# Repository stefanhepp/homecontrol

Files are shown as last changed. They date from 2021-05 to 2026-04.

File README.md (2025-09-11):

HomeControl
===========

This is the sourcecode and plans for my home automation system.

Content
=======

- `homecontrol`: Sources and schematics for a simple AtMega based home automation controller with 8 24VDC digital inputs, 8 24VDC digital outputs (open collector), RS232 and 2 230VAC sense inputs.
- `pixtend`: Sources for the main controller, based on an PiXtend v2-S with Raspberry 3B, written in Python. Connects via RS232 and MQTT to the network.

Installation Pixtend OS
=======================

- Install Raspbian OS (64bit)
   - `sudo rpi-imager`: Enable SSH, set hostname, username, password
- Setup Rasbian, install software
  ```
  # Enable SPI, UART, console bootup, set locale
  sudo raspi-config
  sudo apt install vim screen git gpiod libgpiod-dev python3-dev python3-pip python3-paho-mqtt
  ```
- Install Pixtend Python library
  ```
  git clone https://git.kontron-electronics.de/sw/ked/raspberry-pi/pixtend-v2/pplv2.git
  cd pplv2
  git checkout 0.1.6-dev
  python setup.py bdist_wheel
  # Install into venv
  python -m venv ~/.venv
  source ~/.venv/bin/activate
  pip install dist/pixtendlibv2-0.1.6-py3-none-any.whl
  ```
- Install pixcontrol script
  ```
  # Install prerequisites
  . ~/.venv/bin/activate
  pip install pyserial paho-mqtt
  cd ~/homecontrol/pixtend
  sudo cp pixcontrol.service /etc/systemd/system/
  sudo systemctl enable pixcontrol
  ```

License
=======

This program is free software: you can redistribute it and/or modify
it under the terms of the GNU General Public License as published by
the Free Software Foundation, either version 3 of the License, or
(at your option) any later version.

This program is distributed in the hope that it will be useful,
but WITHOUT ANY WARRANTY; without even the implied warranty of
MERCHANTABILITY or FITNESS FOR A PARTICULAR PURPOSE.  See the
GNU General Public License for more details.

You should have received a copy of the GNU General Public License
along with this program.  If not, see <https://www.gnu.org/licenses/>.

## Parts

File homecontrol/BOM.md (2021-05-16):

Parts for HomeControl
=====================

Case
----
- DMB-4773-CC
  Datasheet: https://www.budind.com/pdf/hb4773.pdf
  Digikey: https://www.digikey.at/product-detail/de/bud-industries/DMB-4773/377-1810-ND/2499329

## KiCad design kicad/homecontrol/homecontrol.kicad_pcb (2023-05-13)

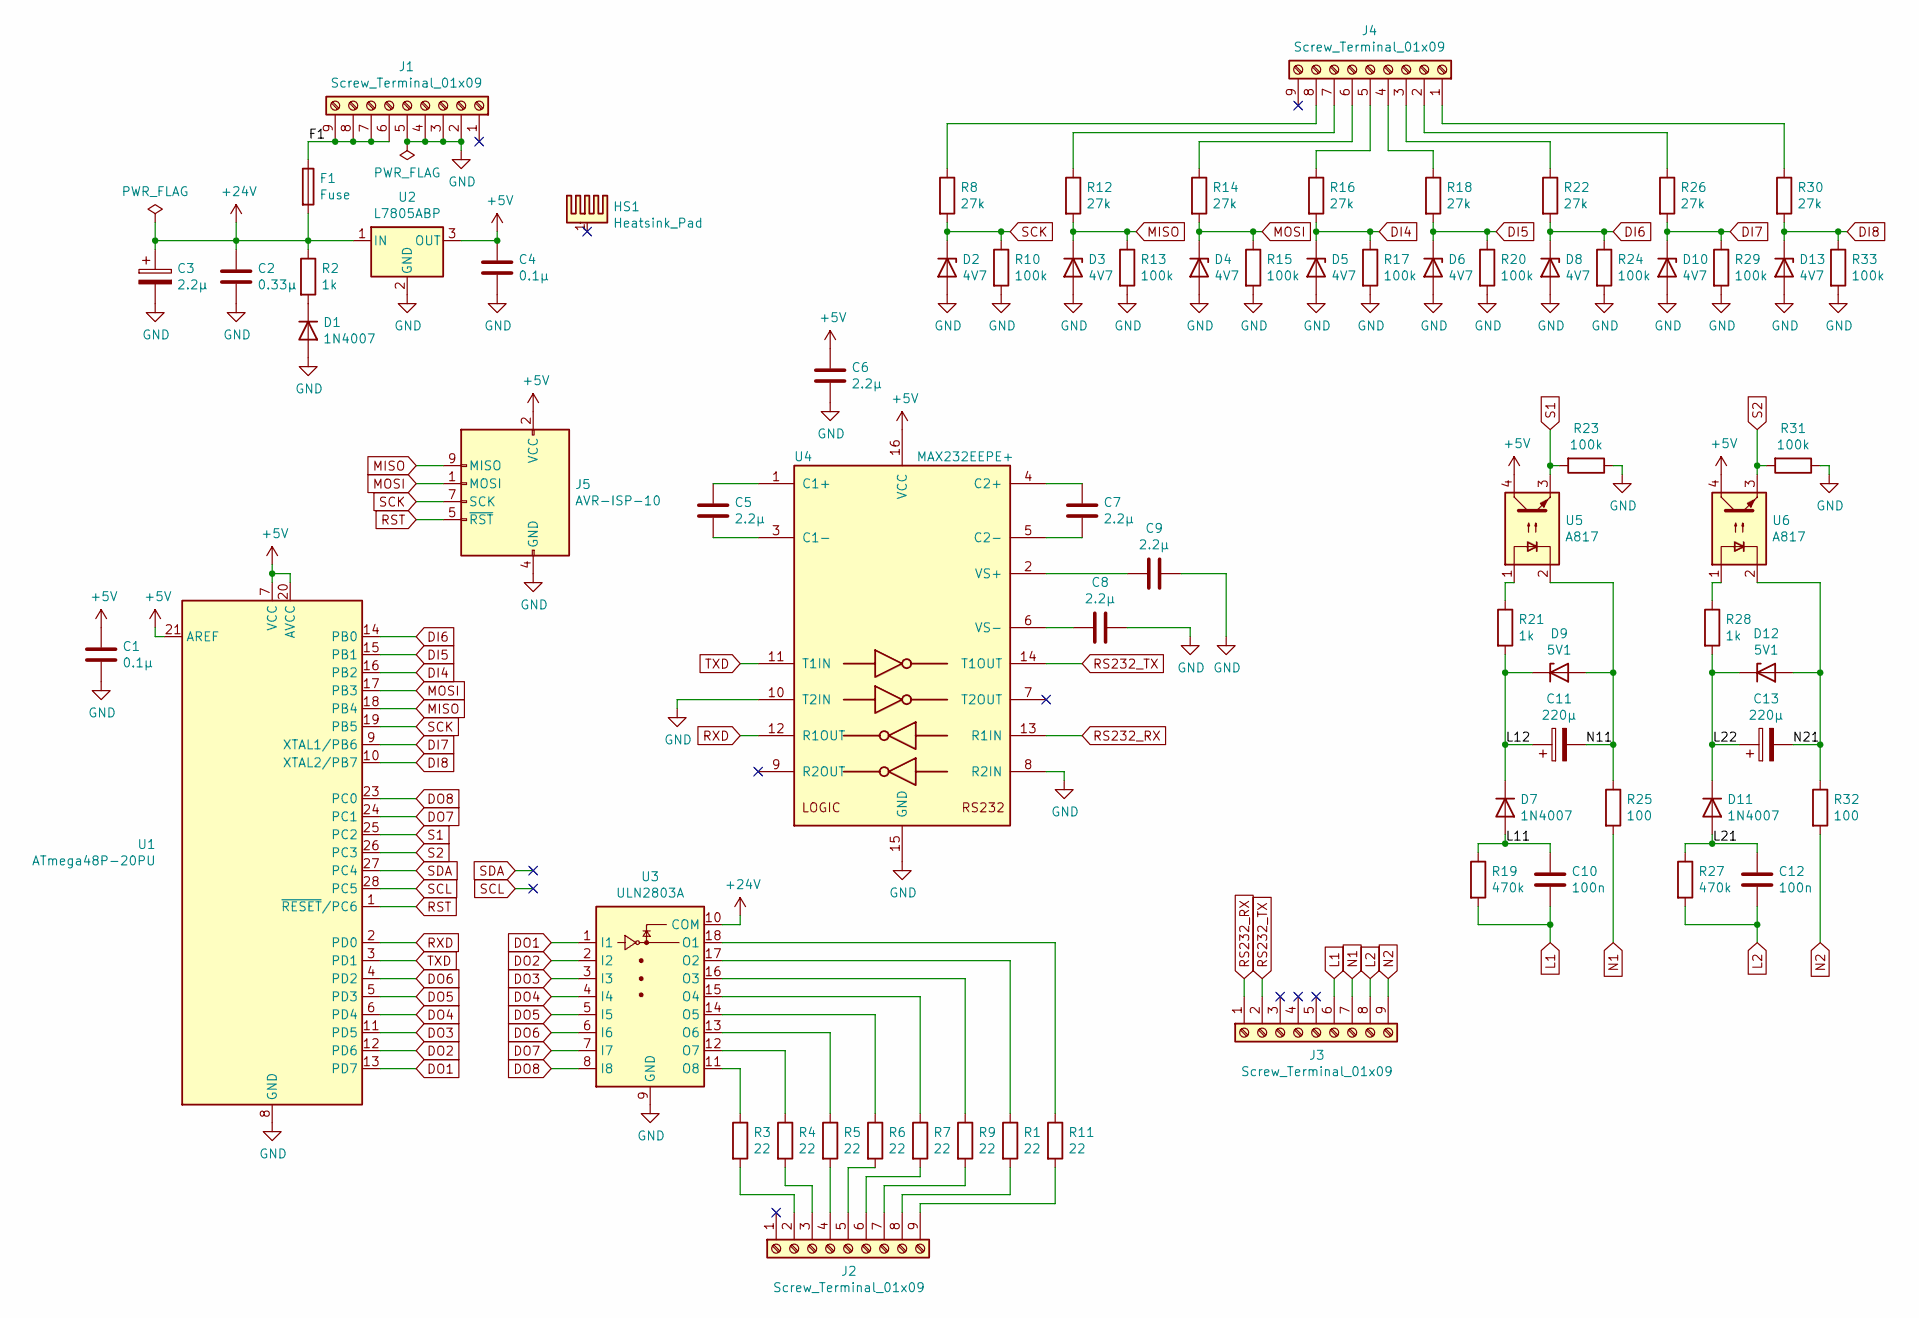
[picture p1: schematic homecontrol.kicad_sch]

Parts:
C1, C4: 0.1µ; C_Rect_L7.0mm_W2.5mm_P5.00mm; Voltage 50V
C2: 0.33µ; C_Disc_D4.7mm_W2.5mm_P5.00mm; Voltage 50V
C3: 2.2µ; CP_Radial_D6.3mm_P2.50mm; Voltage 50V
C5, C6, C7, C8, C9: 2.2µ; C_Rect_L4.6mm_W3.0mm_P2.50mm_MKS02_FKP02; Voltage 50V
C10, C12: 100n; C_Rect_L19.0mm_W6.0mm_P15.00mm_MKS4; Voltage 250V
C11, C13: 220µ; CP_Radial_D6.3mm_P2.50mm; Voltage 16V
D1: 1N4007; D_DO-35_SOD27_P2.54mm_Vertical_KathodeUp
D2, D3, D4, D5, D6, D8, D10, D13: 4V7; D_DO-35_SOD27_P2.54mm_Vertical_KathodeUp
D7, D11: 1N4007; D_DO-201AD_P3.81mm_Vertical_KathodeUp
D9, D12: 5V1; D_DO-35_SOD27_P2.54mm_Vertical_KathodeUp
F1: Fuse; Fuseholder_Cylinder-5x20mm_Schurter_0031_8201_Horizontal_Op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
HS1: Heatsink_Pad; Heatsink_Aavid_TO-220_H12.7mm
J1, J2, J3, J4: Screw_Terminal_01x09; TerminalBlock_Phoenix_MKDS-1,5-9-5.08_1x09_P5.08mm_Horizont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
J5: AVR-ISP-10; IDC-Header_2x05_P2.54mm_Vertical
R1, R3, R4, R5, R6, R7, R9, R11: 22; R_Axial_DIN0207_L6.3mm_D2.5mm_P2.54mm_Vertical
R2, R21, R28: 1k; R_Axial_DIN0207_L6.3mm_D2.5mm_P2.54mm_Vertical
R8, R12, R14, R16, R18, R22, R26, R30: 27k; R_Axial_DIN0207_L6.3mm_D2.5mm_P2.54mm_Vertical
R10, R13, R15, R17, R20, R23, R24, R29, R31, R33: 100k; R_Axial_DIN0207_L6.3mm_D2.5mm_P2.54mm_Vertical
R19, R27: 470k; R_Axial_DIN0207_L6.3mm_D2.5mm_P10.16mm_Horizontal
R25, R32: 100; R_Axial_DIN0207_L6.3mm_D2.5mm_P10.16mm_Horizontal
U1: ATmega48P-20PU; DIP-28_W7.62mm_Socket
U2: L7805ABP; TO-220-3_Vertical
U3: ULN2803A; DIP-18_W7.62mm_Socket
U4: MAX232EEPE+; DIP-16_W7.62mm_Socket
U5, U6: A817; DIP-4_W7.62mm

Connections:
+5V: C1.1, C4.1, C6.1, J5.2 (VCC), U1.7 (VCC), U1.20 (AVCC), U1.21 (AREF), U2.3 (OUT), U4.16 (VCC), U5.4, U6.4
+24V: C2.1, C3.1, F1.2, R2.1, U2.1 (IN), U3.10 (COM)
/F1: F1.1, J1.6, J1.7, J1.8, J1.9
/L11: C10.2, D7.2 (A), R19.1
/L12: C11.1, D7.1 (K), D9.1 (K), R21.2
/L21: C12.2, D11.2 (A), R27.1
/L22: C13.1, D11.1 (K), D12.1 (K), R28.2
/N11: C11.2, D9.2 (A), R25.1, U5.2
/N21: C13.2, D12.2 (A), R32.1, U6.2
DI4: D5.1 (K), R16.2, R17.1, U1.16 (PB2)
DI5: D6.1 (K), R18.2, R20.1, U1.15 (PB1)
DI6: D8.1 (K), R22.2, R24.1, U1.14 (PB0)
DI7: D10.1 (K), R26.2, R29.1, U1.9 (XTAL1/PB6)
DI8: D13.1 (K), R30.2, R33.1, U1.10 (XTAL2/PB7)
DO1: U1.13 (PD7), U3.1 (I1)
DO2: U1.12 (PD6), U3.2 (I2)
DO3: U1.11 (PD5), U3.3 (I3)
DO4: U1.6 (PD4), U3.4 (I4)
DO5: U1.5 (PD3), U3.5 (I5)
DO6: U1.4 (PD2), U3.6 (I6)
DO7: U1.24 (PC1), U3.7 (I7)
DO8: U1.23 (PC0), U3.8 (I8)
GND: C1.2, C2.2, C3.2, C4.2, C6.2, C8.1, C9.1, D1.2 (A), D2.2 (A), D3.2 (A), D4.2 (A), D5.2 (A), D6.2 (A), D8.2 (A), D10.2 (A), D13.2 (A), J1.2, J1.3, J1.4, J1.5, J5.4 (GND), J5.6 (GND), J5.8 (GND), J5.10 (GND), R10.2, R13.2, R15.2, R17.2, R20.2, R23.1, R24.2, R29.2, R31.1, R33.2, U1.8 (GND), U1.22 (GND), U2.2 (GND), U3.9 (GND), U4.8 (R2IN), U4.10 (T2IN), U4.15 (GND)
L1: C10.1, J3.6, R19.2
L2: C12.1, J3.8, R27.2
MISO: D3.1 (K), J5.9 (MISO), R12.2, R13.1, U1.18 (PB4)
MOSI: D4.1 (K), J5.1 (MOSI), R14.2, R15.1, U1.17 (PB3)
N1: J3.7, R25.2
N2: J3.9, R32.2
unnamed: D1.1 (K), R2.2
unnamed: J2.2, R3.2
unnamed: J2.3, R4.2
unnamed: J2.4, R5.2
unnamed: J2.5, R6.2
unnamed: J2.6, R7.2
unnamed: J2.7, R9.2
unnamed: J2.8, R1.2
unnamed: J2.9, R11.2
unnamed: J4.1, R30.1
unnamed: J4.2, R26.1
unnamed: J4.3, R22.1
unnamed: J4.4, R18.1
unnamed: J4.5, R16.1
unnamed: J4.6, R14.1
unnamed: J4.7, R12.1
unnamed: J4.8, R8.1
unnamed: R21.1, U5.1
unnamed: R28.1, U6.1
unnamed: R11.1, U3.18 (O1)
unnamed: R1.1, U3.17 (O2)
unnamed: R9.1, U3.16 (O3)
unnamed: R7.1, U3.15 (O4)
unnamed: R6.1, U3.14 (O5)
unnamed: R5.1, U3.13 (O6)
unnamed: R4.1, U3.12 (O7)
unnamed: R3.1, U3.11 (O8)
unnamed: C5.1, U4.1 (C1+)
unnamed: C5.2, U4.3 (C1-)
unnamed: C7.1, U4.4 (C2+)
unnamed: C7.2, U4.5 (C2-)
unnamed: C9.2, U4.2 (VS+)
unnamed: C8.2, U4.6 (VS-)
RS232_RX: J3.1, U4.13 (R1IN)
RS232_TX: J3.2, U4.14 (T1OUT)
RST: J5.5 (~RST), U1.1 (~RESET/PC6)
RXD: U1.2 (PD0), U4.12 (R1OUT)
S1: R23.2, U1.25 (PC2), U5.3
S2: R31.2, U1.26 (PC3), U6.3
SCK: D2.1 (K), J5.7 (SCK), R8.2, R10.1, U1.19 (PB5)
SCL: U1.28 (PC5)
SDA: U1.27 (PC4)
TXD: U1.3 (PD1), U4.11 (T1IN)

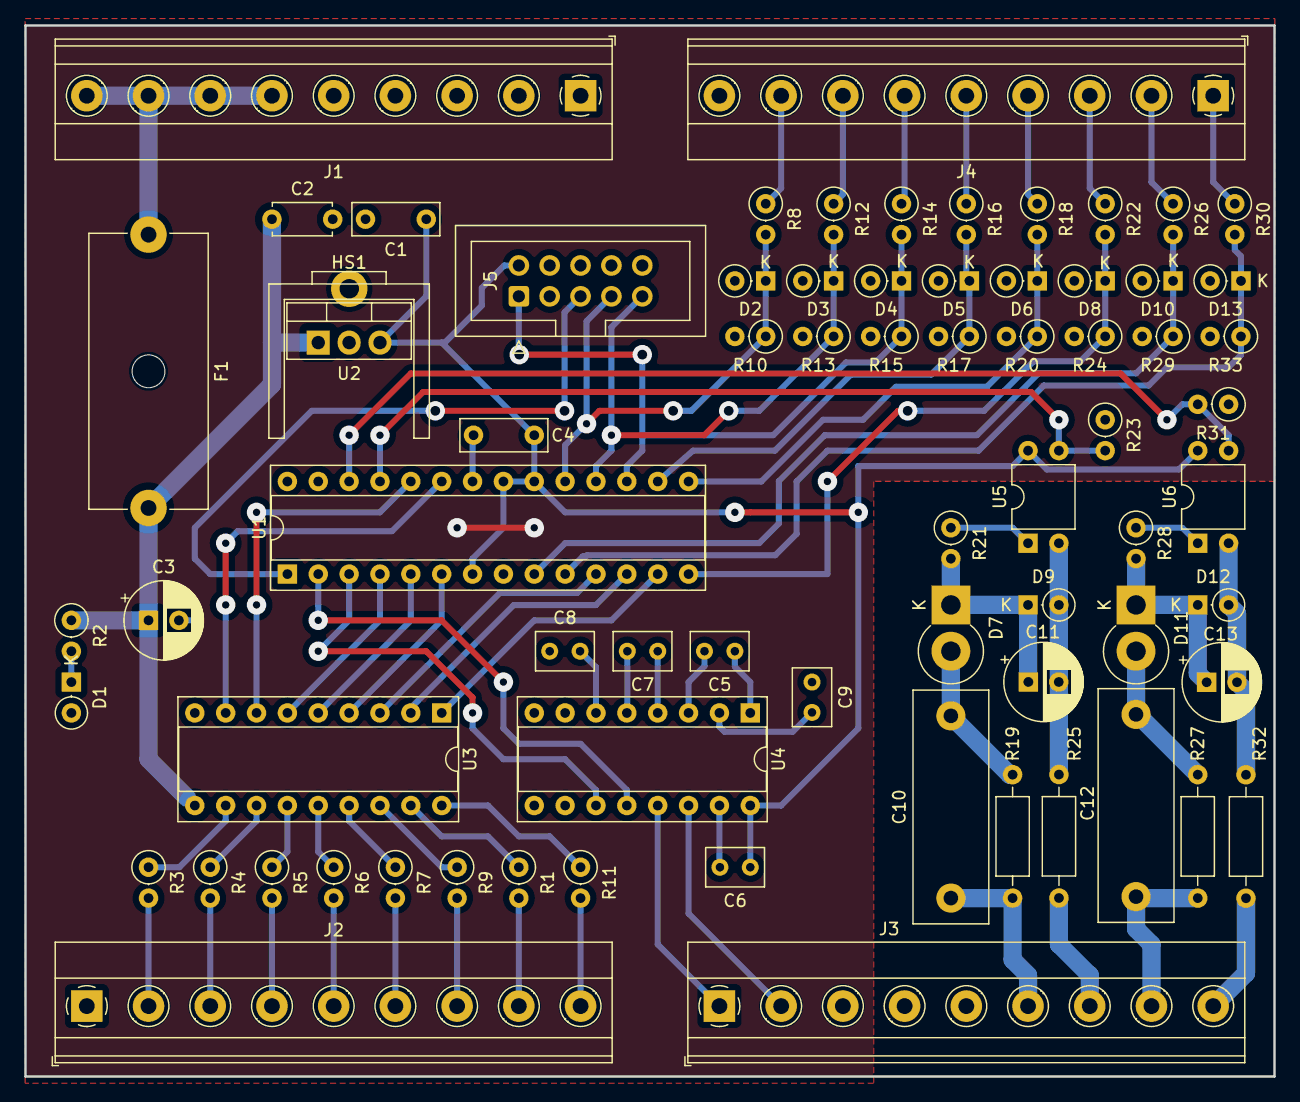
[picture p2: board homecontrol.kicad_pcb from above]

Board: 2 copper layers, 102.8 x 86.5 mm, 72 parts (0 on the bottom side), 70 nets.

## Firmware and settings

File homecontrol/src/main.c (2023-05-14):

/**
 * Project:   HomeControl
 * File:      main.c
 * Author:    Stefan Hepp <stefan@stefant.org>
 *
 * Copyright 2018 Stefan Hepp
 *
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
 * Main control code for HomeControl.
 *
 * Pinout:
 * - PortB:
 *   - PB0: DIn6
 *   - PB1: DIn5
 *   - PB2: DIn4 - Stair-Staircase
 *   - PB3: DIn3 - Stair-Light
 *   - PB4: DIn2 - Staircase
 *   - PB5: DIn1 - Livingroom
 *   - PB6: DIn7
 *   - PB7: DIn8
 * - PortC:
 *   - PC0: DOut1 - Livingroom
 *   - PC1: DOut2 - Staircase
 *   - PC2: Sense In 1 - Stair Sense
 *   - PC3: Sense In 2
 *   - PC4: SDA
 *   - PC5: SCL
 *   - PC6: Reset In
 * - PortD:
 *   - PD0: RXD
 *   - PD1: TXD
 *   - PD2: DOut3 - Stair-Light
 *   - PD3: DOut4 - Stair-Sense
 *   - PD4: DOut5
 *   - PD5: DOut6
 *   - PD6: DOut7
 *   - PD7: DOut8
 **/

// Define CPU clock speed and UART baud rate
#define F_CPU 1000000
#define BAUD  9600

#include <avr/io.h>
#include <avr/interrupt.h>
#include <avr/sleep.h>

// Baud rate calculation, delays
#include <util/setbaud.h>
#include <util/delay.h>

#define SET_BIT(port,pin,value) \
    if (value) { \
	port |= _BV(pin);  \
    } else { \
	port &= ~_BV(pin); \
    }

/**
 * IO Mapping
 **/
#define PB_DIN1 PB5
#define PB_DIN2 PB4
#define PB_DIN3 PB3
#define PB_DIN4 PB2
#define PB_DIN5 PB1
#define PB_DIN6 PB0
#define PB_DIN7 PB6
#define PB_DIN8 PB7

#define PC_SENSE1 PC2
#define PC_SENSE2 PC3

#define PC_DOUT1 PC0
#define PC_DOUT2 PC1
#define PD_DOUT3 PD2
#define PD_DOUT4 PD3
#define PD_DOUT5 PD4
#define PD_DOUT6 PD5
#define PD_DOUT7 PD6
#define PD_DOUT8 PD7

/**
 * UART command codes
 **/
// Command header
#define UART_CMD_HEADER        0x70

// Command Opcodes:
// - Living room light. Value = 0: Off, 1: Light on, 2: Long press
#define UART_CMD_LIVINGROOM    0x01
// - Stair case light. Value = 0: Off, 1: Light on, 2: Stair long press
#define UART_CMD_STAIRCASE     0x02
// - Stair light. Value = 000000 | Stair Sense | Stair Light
#define UART_CMD_STAIR         0x03
// - All off. Value = 1: All off
#define UART_CMD_ALL_OFF       0x04
// - Status. Value = 000 | Sense | Stair Sense | Stair Light | Staircase | Livingroom
#define UART_CMD_STATUS        0x05
// - Sense notification. Value = 0: Motion Timeout, 1: Motion detected
#define UART_CMD_SENSE         0x06

#define P_OFF     0
// Short press event
#define P_SHORT   1
// Long press event
#define P_LONG    2
// pressed but not yet released
#define P_PRESSED 3

typedef struct {
    // current button pin state
    unsigned char  state;
    // button event state
    unsigned char  pressed;
    // countdown for long button press in 100ms steps. If non-zero, countdown is running
    unsigned short time_longpress;
} switch_t;

// Input switches
switch_t SW_Livingroom;
switch_t SW_Staircase;
switch_t SW_Stair_Light;
switch_t SW_Stair_Staircase;

switch_t SW_Stair_Sense;

// Output states
unsigned char DO_Livingroom = 0;
unsigned char DO_Staircase  = 0;
unsigned char DO_Stair_Light = 0;
unsigned char DO_Stair_Sense = 0;

unsigned char Last_input = 0;

#define UART_BUF_SZ  8

typedef struct {
    unsigned char start;
    unsigned char len;
    unsigned char buf[UART_BUF_SZ];
} uart_buf_t;

uart_buf_t UART_TX_Buf;
uart_buf_t UART_RX_Buf;

void sleep(void)
{
    cli();

    // Only sleep it there is no input change since last read
    if (Last_input == PINB) {
	sleep_enable();
	sleep_bod_disable();
	sei();
	sleep_cpu();
	sleep_disable();
    } else {
	sei();
    }
}

/**
 * Start the long-press timer for that switch
 */
void start_timer(switch_t *sw)
{
    // Start timer with 1.8s
    sw->time_longpress = 18;
    // Enable timer
    TCCR1B = 0x1D;
}

void init_timer(void)
{
    // Fast PWM mode, OCR1A top (mode 15), prescaler clk/1024
    TCCR1A = 0x03;
    TCCR1B = 0x18;

    // Set timer to 100ms
    OCR1A = ((F_CPU/1024)/10);

    // Enable interrupts
    TIMSK1 = _BV(OCIE1A);
}

/**
 * Update switch status on 100ms timer events.
 *
 * \return 1 if switch requires another timer event, else 0.
 */
char update_timer(switch_t *sw)
{
    if (sw->pressed != P_PRESSED) {
	// Disable timer if switch is released (set to SHORT in the meantime)
	sw->time_longpress = 0;
	return 0;
    }
    if (sw->time_longpress) {
	sw->time_longpress--;
	if (sw->time_longpress > 0) {
	    return 1;
	} else {
	    // Set to LONG press event when countdown finishes, even if button is still pressed
	    sw->pressed = P_LONG;
	    return 0;
	}
    }
    return 0;
}

ISR(TIMER1_COMPA_vect)
{
    unsigned char cnt = 0;

    cnt += update_timer(&SW_Staircase);
    cnt += update_timer(&SW_Stair_Light);
    cnt += update_timer(&SW_Stair_Staircase);

    if (cnt == 0) {
	// Stop timer
	TCCR1B = 0x18;
    }
}

ISR(PCINT0_vect)
{
    // Register interrupt handler to wakeup CPU
}

void init_switch(switch_t *sw)
{
    sw->state = 0;
    sw->pressed = P_OFF;
    sw->time_longpress = 0;
}

/**
 * Update the status of a toggle switch from an pin input.
 */
void update_switch(switch_t *sw, unsigned char value)
{
    if (sw->state != value) {
	sw->pressed = P_SHORT;
    }
    sw->state = value;
}

/**
 * Update the status of a push button from an pin input.
 */
void update_button(switch_t *sw, unsigned char value)
{
    if (!sw->state && value) {
	start_timer(sw);
	sw->pressed = P_PRESSED;
    }
    if (sw->state && !value) {
	// If the timer runs out, this gets set to LONG
	if (sw->pressed == P_PRESSED) {
	    sw->pressed = P_SHORT;
	}
    }
    sw->state = value;
}

/**
 * Add a value to a FIFO buffer.
 */
void buf_push(uart_buf_t *buf, unsigned char value)
{
    if (buf->len < UART_BUF_SZ) {
	buf->buf[ (buf->start + buf->len) % UART_BUF_SZ ] = value;
	buf->len++;
    }
}

/**
 * Remove a value from a FIFO buffer.
 * \return the buffer, or 0 if the buffer is empty
 */
unsigned char buf_pop(uart_buf_t *buf)
{
    unsigned char ret = 0;

    if (buf->len > 0) {
	ret = buf->buf[buf->start];
	buf->start = (buf->start + 1) % UART_BUF_SZ;
	buf->len--;
    }
    return ret;
}

/**
 * Handle receiving a character from UART.
 */
ISR(USART_RX_vect)
{
    buf_push( &UART_RX_Buf, UDR0 );
}

/**
 * Send the next character when the send buffer is empty.
 */
ISR(USART_UDRE_vect)
{
    if (UART_TX_Buf.len > 0) {
	// Send the next character from the buffer
	UDR0 = buf_pop( &UART_TX_Buf );
    } else {
	// Stop transmitting
	UCSR0B &= ~_BV( UDRIE0 );
    }
}

/**
 * Init UART.
 **/
void init_uart(void)
{
    // Set baud rate
    UBRR0H = UBRRH_VALUE;
    UBRR0L = UBRRL_VALUE;
#if USE_2X
    UCSR0A |= _BV(U2X0);
#else
    UCSR0A &= ~_BV(U2X0);
#endif
    // Enable RX and TX, RX interrupts
    UCSR0B = _BV(RXEN0) | _BV(TXEN0) | _BV(RXCIE0);
    // Set frame format: 8N1
    UCSR0C = (3 << UCSZ00);
}

/**
 * Send a command via UART
 */
void send_command(unsigned char cmd, unsigned char value)
{
    cli();
    buf_push( &UART_TX_Buf, UART_CMD_HEADER | cmd );
    buf_push( &UART_TX_Buf, value );
    sei();

    // Start transmitting (enable UDRE interrupt on empty buffer)
    UCSR0B |= _BV( UDRIE0 );
}

/**
 * Read a command received from UART.
 * \return 1 if a command is received, else 0.
 */
char read_command(unsigned char *cmd, unsigned char *value)
{
    // We need at least 2 characters in the buffer for a valid message
    cli();
    while (UART_RX_Buf.len > 1) {
	*cmd = buf_pop(&UART_RX_Buf);
	if ((*cmd & UART_CMD_HEADER) == UART_CMD_HEADER) {
	    if (UART_RX_Buf.len > 0) {
		*cmd &= ~(UART_CMD_HEADER);
		*value = buf_pop(&UART_RX_Buf);
		sei();
		return 1;
	    } else {
		// Not yet enough data
		buf_push(&UART_RX_Buf, *cmd);
		sei();
		return 0;
	    }
	}
    }
    sei();
    return 0;
}

void send_status(void)
{
    unsigned char status = 0;

    status |= SW_Stair_Sense.state << 4;
    status |= DO_Stair_Sense << 3;
    status |= DO_Stair_Light << 2;
    status |= DO_Staircase   << 1;
    status |= DO_Livingroom;

    send_command(UART_CMD_STATUS, status);
}

/**
 * Turn all lights off
 */
void cmd_all_off(void)
{
    DO_Livingroom = 0;
    DO_Staircase = 0;
    if (DO_Stair_Light) {
	DO_Stair_Sense = 1;
    }
    DO_Stair_Light = 0;
}

/**
 * Read all input pins and update switch status.
 */
void read_inputs(void)
{
    Last_input = PINB;

    update_switch(&SW_Livingroom,      Last_input & (1 << PB_DIN1) ? 1 : 0);
    update_button(&SW_Staircase,       Last_input & (1 << PB_DIN2) ? 1 : 0);
    update_button(&SW_Stair_Light,     Last_input & (1 << PB_DIN3) ? 1 : 0);
    update_button(&SW_Stair_Staircase, Last_input & (1 << PB_DIN4) ? 1 : 0);

    update_switch(&SW_Stair_Sense,     bit_is_set(PINC, PC_SENSE1) ? 1 : 0);
}

/**
 * Handle all UART commands.
 */
void process_uart(void)
{
    unsigned char cmd;
    unsigned char value;

    while (read_command(&cmd, &value)) {
	switch (cmd) {
	    case UART_CMD_LIVINGROOM:
		DO_Livingroom = value & 0x01;
		break;
	    case UART_CMD_STAIRCASE:
		DO_Staircase = value & 0x01;
		break;
	    case UART_CMD_STAIR:
		DO_Stair_Sense = (value >> 1) & 0x01;
		DO_Stair_Light =  value       & 0x01;
		break;
	    case UART_CMD_ALL_OFF:
		cmd_all_off();
		break;
	    case UART_CMD_STATUS:
		send_status();
		break;
	    case UART_CMD_SENSE:
		send_command(UART_CMD_SENSE, SW_Stair_Sense.state);
		break;
	}
    }
}

/**
 * Update outputs based on input switches.
 */
void process_inputs(void)
{
    // Living room switch
    if (SW_Livingroom.pressed == P_SHORT) {
	// Toggle living room
	DO_Livingroom ^= 1;
	send_command(UART_CMD_LIVINGROOM, DO_Livingroom);
    }
    if (SW_Livingroom.pressed == P_LONG) {
	// Send UART command
	send_command(UART_CMD_LIVINGROOM, 2);
    }

    // Staircase switch
    if (SW_Staircase.pressed == P_SHORT) {
	// Toggle staircase
	DO_Staircase ^= 1;
	send_command(UART_CMD_STAIRCASE, DO_Staircase);
    }
    if (SW_Staircase.pressed == P_LONG) {
	// All off
	cmd_all_off();
	send_command(UART_CMD_ALL_OFF, 1);
	send_status();
    }

    // Stair light switch
    if (SW_Stair_Light.pressed == P_SHORT) {
	// Toggle On > Sensor <> Off
	if (DO_Stair_Light) {
	    DO_Stair_Light = 0;
	    DO_Stair_Sense = 1;
	} else {
	    DO_Stair_Sense ^= 1;
	}
	send_command(UART_CMD_STAIR, (DO_Stair_Sense << 1) | DO_Stair_Light);
    }
    if (SW_Stair_Light.pressed == P_LONG) {
	// Toggle light on/off, sensor off
	DO_Stair_Light ^= 1;
        DO_Stair_Sense = 0;
	send_command(UART_CMD_STAIR, (DO_Stair_Sense << 1) | DO_Stair_Light);
    }

    // Outside stair staircase switch
    if (SW_Stair_Staircase.pressed == P_SHORT) {
	// Toggle staircase
	DO_Staircase ^= 1;
	send_command(UART_CMD_STAIRCASE, DO_Staircase);
    }
    if (SW_Stair_Staircase.pressed == P_LONG) {
	// Send UART command
	send_command(UART_CMD_STAIRCASE, 2);
    }

    // Motion sense input
    if (SW_Stair_Sense.pressed != P_OFF) {
	send_command(UART_CMD_SENSE, SW_Stair_Sense.state);
    }

    // All new inputs processed, clear status
    if (SW_Livingroom.pressed != P_PRESSED) {
	SW_Livingroom.pressed = P_OFF;
    }
    if (SW_Staircase.pressed != P_PRESSED) {
	SW_Staircase.pressed = P_OFF;
    }
    if (SW_Stair_Light.pressed != P_PRESSED) {
	SW_Stair_Light.pressed = P_OFF;
    }
    if (SW_Stair_Staircase.pressed != P_PRESSED) {
        SW_Stair_Staircase.pressed = P_OFF;
    }
    SW_Stair_Sense.pressed = P_OFF;
}

void write_outputs(void)
{
    SET_BIT(PORTC, PC_DOUT1, DO_Livingroom);
    SET_BIT(PORTC, PC_DOUT2, DO_Staircase);
    SET_BIT(PORTD, PD_DOUT3, DO_Stair_Light);
    SET_BIT(PORTD, PD_DOUT4, DO_Stair_Sense);
}

/**
 * Init IO ports.
 */
void init_io(void)
{
    // Port B: Input, external pull-down
    DDRB = 0x00;
    PORTB = 0x00;

    // Port C: 0,1: Output; 2-3: Input, pull-down; 4-6: Input pull-up
    DDRC = 0x03;
    PORTC = 0xF0;
    
    // Port D: 0: Input, pull-up; 1-7: Output
    DDRD = 0xFE;
    PORTD = 0x01;

    // Enable external interrupts on inputs
    PCMSK0 = 0xFF;
    PCICR = _BV(PCIE0);
}

int main()
{    
    // Disable interrupts
    cli();

    // Setup ports 
    init_io();

    // Configure UART
    init_uart();

    // Configure timer
    init_timer();

    init_switch(&SW_Livingroom);
    init_switch(&SW_Staircase);
    init_switch(&SW_Stair_Light);
    init_switch(&SW_Stair_Staircase);

    // Enable interrupts
    sei();

    while(1) {
	// Wait for any inputs
	//sleep();

	read_inputs();

	process_inputs();

	process_uart();

	write_outputs();

	// Debounce inputs
	_delay_ms(25);
    }

    return 0;
}

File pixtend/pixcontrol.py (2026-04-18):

#!/usr/bin/env python
#
# Project:   HomeControl
# File:      pixcontrol.py
# Author:    Stefan Hepp <stefan@stefant.org>
#
# Copyright 2018 Stefan Hepp
#
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
# Control loop implementation for my home controller.
#
# This software is intended to be run on a PiXtend v2-S board.
#


# Import Pixtend V2 class
from pixtendv2s import PiXtendV2S
import time
import datetime
import sys
import serial
import math
import paho.mqtt.client as mqtt


class Debug:
     # Print Rx and Tx UART messages
    DEBUG_UART_TX = False
    DEBUG_UART_RX = False

    # Debug MQTT messages
    DEBUG_MQTT = False
   

class Button(object):
    OFF        = 0
    SHORT      = 1
    LONG       = 2

    def __init__(self, initstate = False):
        self._state = initstate
        self._status = self.OFF

    @property
    def state(self):
        return self._state

    @property
    def pressed(self):
        return self._status

    def clear(self):
        self._status = self.OFF

class PushButton(Button):
    def __init__(self):
        Button.__init__(self)
        self._time_pressed = None
        self._is_released = False

    def update(self, pressed):
        if self._state is False and pressed is True:
            # Start timer
            self._time_pressed = time.time()
        if self._state is True  and time.time() - self._time_pressed >= 2.5 and self._is_released is False:
            self._status = self.LONG
            self._is_released = True
        if self._state is True  and pressed is False:
            if not self._is_released:
                self._status = self.SHORT
            self._is_released = False
        self._state = pressed

class SwitchButton(Button):
    def __init__(self):
        Button.__init__(self, None)

    def update(self, pressed):
        if self._state is not None and self._state != pressed:
            # Every state change is a press event
            self._status = self.SHORT
        self._state = pressed


class MQTTSerializer(object):
    def serialize(self, value):
        return value

    def deserialize(self, payload):
        return payload

class TableSerializer(MQTTSerializer):
    """ Translate values via a lookup table. """

    def __init__(self, table):
        self._table = table
        self._reverse_table = dict(zip(table.values(), table.keys()))

    def serialize(self, value):
        return self._table.get(value)

    def deserialize(self, payload):
        return self._reverse_table.get(payload)

class TimeSerializer(MQTTSerializer):
    def serialize(self, value):
        return value.strftime("%H:%M")

    def deserialize(self, payload):
        """ Split a H:M string and return a time object, or None if the format does not match """
        t = payload.split(":")
        if len(t) != 2:
            return None
        return datetime.time( int(t[0]), int(t[1]) )


class Signal(object):
    PUBLISH_NONE   = False
    PUBLISH_INPUT  = 1
    PUBLISH_OUTPUT = 2

    def __init__(self, initstate = False):
        self._init = initstate
        self._input = initstate
        self._output = initstate
        self._lastpublish = None
        self._publish = Signal.PUBLISH_NONE
        self._changed = False
        self._translate = TableSerializer( { True: "on", False: "off" } )

    @property
    def translate(self):
        return self._translate

    @translate.setter
    def translate(self, value):
        self._translate = TableSerializer( value )

    def on_message(self, client, userdata, msg):
        payload = msg.payload.decode("ascii")
        data = self._translate.deserialize( str( payload ) )
        if Debug.DEBUG_MQTT:
            print("Received MQTT topic: ", msg.topic, data)
        if data is not None:
            self.update(data, publish=False)

    def publish(self, client, topic, retain = True, subscribe = True, publish = PUBLISH_INPUT):
        self._mqtt = client
        self._topic = topic
        self._retain = retain
        self._publish = publish
        if subscribe:
            self._mqtt.subscribe(topic)
            self._mqtt.message_callback_add(self._topic, lambda c, u, m: self.on_message(c, u, m))
        if publish != Signal.PUBLISH_NONE:
            self._publish_signal(force=True)

    def _publish_signal(self, force=False):
        if self._publish == Signal.PUBLISH_NONE: return

        pubdata = self._input if self._publish == Signal.PUBLISH_INPUT else self._output

        if self._lastpublish != pubdata or force:
            data = self._translate.serialize(pubdata)
            if data is not None:
                self._mqtt.publish(self._topic, data, retain = self._retain)
            self._lastpublish = pubdata

    def update(self, value, publish=True):
        if self._input is not None and self._input != value:
            self._changed = True
        # Update output before setting the new value as last input
        self._update(value)
        self._input = value
        # Publish MQTT data
        if publish:
            self._publish_signal()

    def toggle(self):
        self.update(not self._input)

    @property
    def state(self):
        return self._input

    @property
    def changed(self):
        return self._changed

    def clear(self, reset=False):
        self._changed = False
        if reset:
            self._input = self._init
            self._update(self._init)

    @property
    def output(self, publish=True):
        self._update_output()
        if publish:
            self._publish_signal()
        return self._output

    def _update(self, value):
        pass

    def _update_output(self):
        pass

class StateSignal(Signal):
    def __init__(self, initstate = False):
        Signal.__init__(self, initstate)

    def _update(self, value):
        self._output = value

class PulseSignal(Signal):
    """ Creates a pulse on every state change. """

    def __init__(self, duration = 0.5):
        Signal.__init__(self)
        self._pulse_start = None
        self.duration = duration
    
    def _update(self, value):
        if self._input != value:
            self._pulse_start = time.time()
            self._output = True

    def _update_output(self):
        if self._output and time.time() - self._pulse_start > self.duration:
            self._output = False

class ExtendSignal(Signal):
    """ Extends the length of an input pulse by some duration. """

    def __init__(self, duration = 1.0):
        Signal.__init__(self)
        self._pulse_start = None
        self.duration = duration
    
    def _update(self, value):
        if value:
            self._output = True
        elif self._input:
            # Start timeout for pulse extenstion
            self._pulse_start = time.time()

    def _update_output(self):
        if self._output and not self._input and time.time() - self._pulse_start > self.duration:
            self._output = False
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

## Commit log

2018-09-17 Added UART implementation
2018-09-23 Added timer for long presses, bugfixes. First working version.
    [main.c]
2018-10-05 Changed livingroom switch from pushbutton to switch type
2018-10-05 Implemented blinking leds via PWM
2018-10-09 Implemented UART and MQTT control
2018-10-10 Fixed UART receive, turn off garden light on All Off.
    [pixcontrol.py]
2018-10-10 Added configurable All-Off timer and configurable pump timer intervals
2019-06-01 Added flash script for RaspberryPi avrdude
2019-06-20 Use stair sensor as switch instead of as button
2020-01-15 Changed second doorbell button to door open button
2021-05-16 Added KiCad Schematics for HomeControl
    [homecontrol.kicad_pcb, homecontrol.sch]
2021-05-16 Updated footprints and BOM
    [homecontrol.kicad_pcb, homecontrol.sch]
2021-05-17 First full PCB layout of HomeControl
    [homecontrol.kicad_pcb, homecontrol.sch]
2023-05-13 Updated HomeControl PCB to KiCAD 7.0, fixed MKS4 footprint
    [homecontrol.kicad_pcb, homecontrol.kicad_sch, homecontrol.sch]
2023-05-14 Adapted IO mapping to new PCB layout
    [homecontrol.kicad_sch]
2024-06-30 Fixed MQTT client implementation
    [pixcontrol.py]
2024-11-04 Auto-reset door light mode by timer
    [pixcontrol.py]
2025-09-11 Fixes for python3, added installation instructions
    [pixcontrol.py]
2026-01-07 Disable tvroom lights with All-Off, fixes for Python 3
    [pixcontrol.py]
